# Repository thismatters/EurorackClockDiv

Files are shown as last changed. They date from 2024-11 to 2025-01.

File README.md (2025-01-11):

# Clock Divider (Binary)

This module reduces a clock signal by powers of two.

This is a hobbling together of elements featuring a three-layer stackup with a front face, a layer for all the jacks, and a power/processing layer where all the SMD components are layed out.

The input clock signal is passed through a schmitt trigger which is lifted whole-cloth from the [Yusynth Clock divider](https://yusynth.net/Modular/EN/DIVIDER/index.html) from which the reset signal processing is also lifted.
This module's function is distinct from the aforementioned Yusynth module in that it subdivides the clock by halves. The remainder of the circuit is a bog standard usage of the CD4040.

As with other modules in this line, this clock divider features:
* Polarity protection so that a backward power header doesn't fry anything (twin series schotty diodes: BAT54SL),
* Full surface mount design.

The KiCAD project here uses the library/footprints [found in my companion repo](https://github.com/thismatters/EurorackKiCAD).

## Width

11hp on an [Intellijel 1U rack](https://intellijel.com/support/1u-technical-specifications/).

## Inputs

Jacks:
* Input
* Reset

## Outputs

There are 6 output jacks each outputting a clock signal reduced by the labeled fraction.

## Adjustment

No adjustment required.

## Vendors

There are part numbers in the [BOM](clkdiv.csv) for many of the parts (not for basic passives though) at the following vendors:

* [Mouser](https://www.mouser.com): Needs no introduction. Get your ICs from here (or [digikey](https://www.digikey.com)).
* [Tayda Electronics](https://www.taydaelectronics.com/): Good supplier for passive components; audio jacks, and potentiometers. Their audio jacks are slightly smaller than the thonkiconn from thonk.
* [Love My Switches](https://lovemyswitches.com/): Has [really good knobs](https://lovemyswitches.com/anodized-aluminum-knob-the-lo-fi-1-4-smooth-shaft-12-5mm-od/) to go on those potentiometers!
* [OSHPark](https://oshpark.com/): Fast and (relatively) cheap PCB manufacturer. [V0 PCB](https://oshpark.com/shared_projects/ADWTtPJV)

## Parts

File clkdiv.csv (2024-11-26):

# | Reference | Qty | Value | Footprint | DNP | Vendor | PartNum
1 | C1, C2 | 2 | 22u 50V | Capacitor_THT:CP_Radial_D5.0mm_P2.50mm
2 | C3 | 1 | 100n | Capacitor_SMD:C_0805_2012Metric
3 | C4 | 1 | 47n box | Capacitor_THT:C_Rect_L7.2mm_W2.5mm_P5.00mm_FKS2_FKP2_MKS2_MKP2
4 | D1, D2 | 2 | BAT54S | Package_TO_SOT_SMD:SOT-23 |  | Mouser | 863-BAT54SLT1G
5 | D3, D4, D5 | 3 | 1N4148 | Diode_SMD:D_SOD-323_HandSoldering
6 | J1 | 1 | Conn_02x05_Odd_Even | Eurorack:PinHeader_2x05_P2.54mm_Vertical |  | Tayda | A-2939
7 | J2, J3, J4, J5, J6, J7, J8, J9 | 8 | AudioJack2_SwitchT | Eurorack:AudioJack2_Tayda_A-2566 |  | Tayda | A-2566
8 | J10, J12, J14 | 3 | Conn_01x03_Pin | Connector_PinHeader_2.54mm:PinHeader_1x03_P2.54mm_Vertical
9 | J11, J13, J15 | 3 | Conn_01x03_Socket | Connector_PinSocket_2.54mm:PinSocket_1x03_P2.54mm_Vertical
10 | Q3, Q4 | 2 | BCM847 | Package_SO:TSOP-6_1.65x3.05mm_P0.95mm |  | Mouser | 771-BCM847DS135
11 | R1, R2 | 2 | 10 | Resistor_SMD:R_0805_2012Metric
12 | R3, R9 | 2 | 1M | Resistor_SMD:R_0805_2012Metric
13 | R4 | 1 | 1.2M | Resistor_SMD:R_0805_2012Metric
14 | R5, R6, R12 | 3 | 22K | Resistor_SMD:R_0805_2012Metric
15 | R7 | 1 | 220 | Resistor_SMD:R_0805_2012Metric
16 | R8 | 1 | 100K | Resistor_SMD:R_0805_2012Metric
17 | R10 | 1 | 10K | Resistor_SMD:R_0805_2012Metric
18 | R11 | 1 | 220K | Resistor_SMD:R_0805_2012Metric
19 | R13, R14, R15, R16, R17, R18, R19 | 7 | 1K | Resistor_SMD:R_0805_2012Metric
20 | U1 | 1 | 4040 | Package_SO:TSSOP-16_4.4x5mm_P0.65mm |  | Mouser | 595-CD4040BPWR

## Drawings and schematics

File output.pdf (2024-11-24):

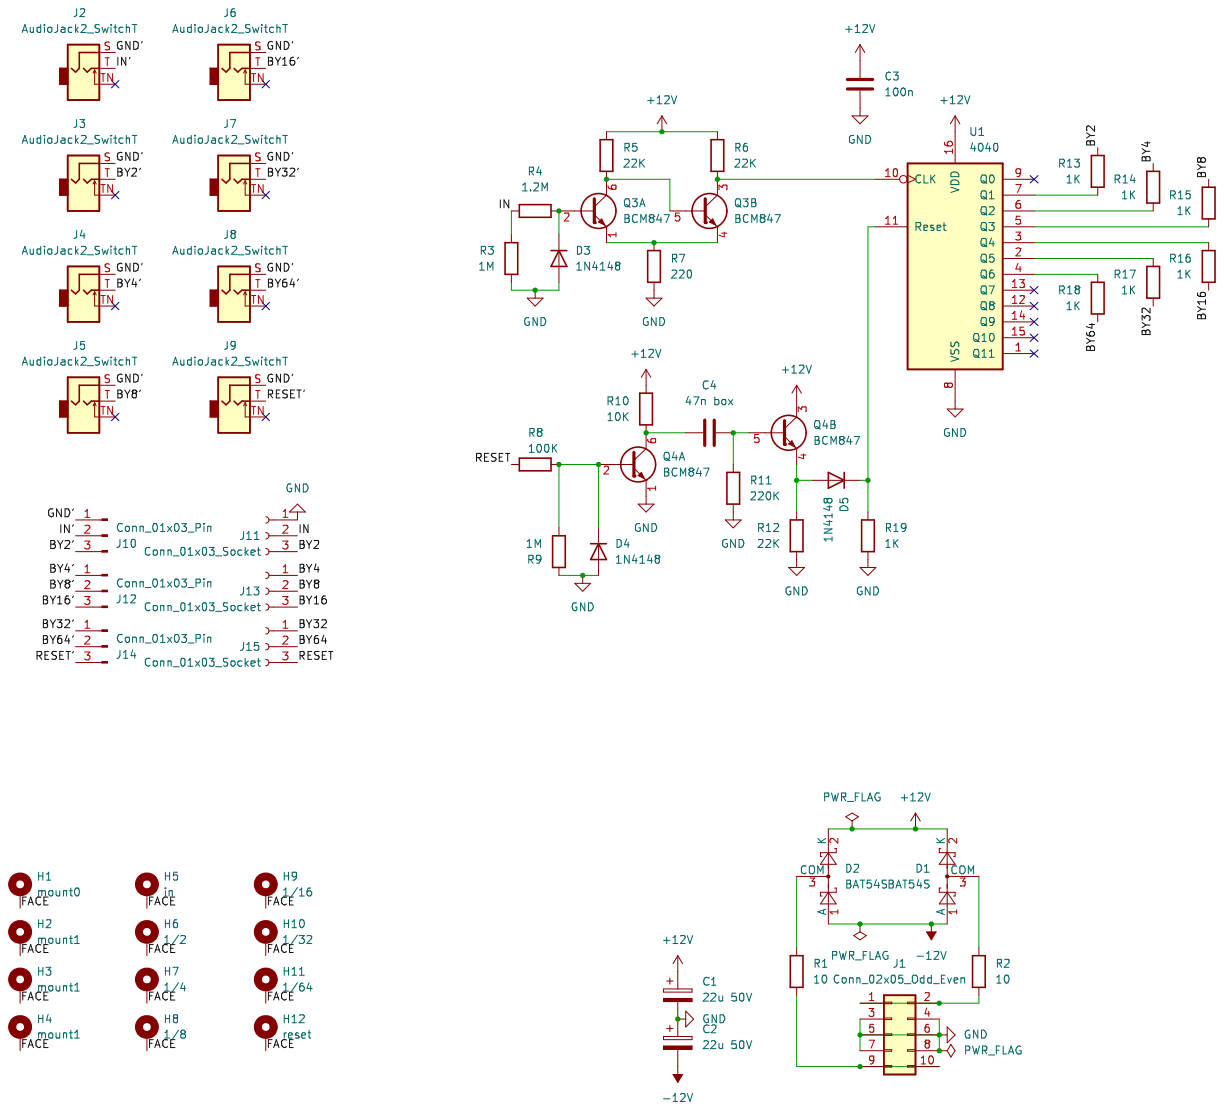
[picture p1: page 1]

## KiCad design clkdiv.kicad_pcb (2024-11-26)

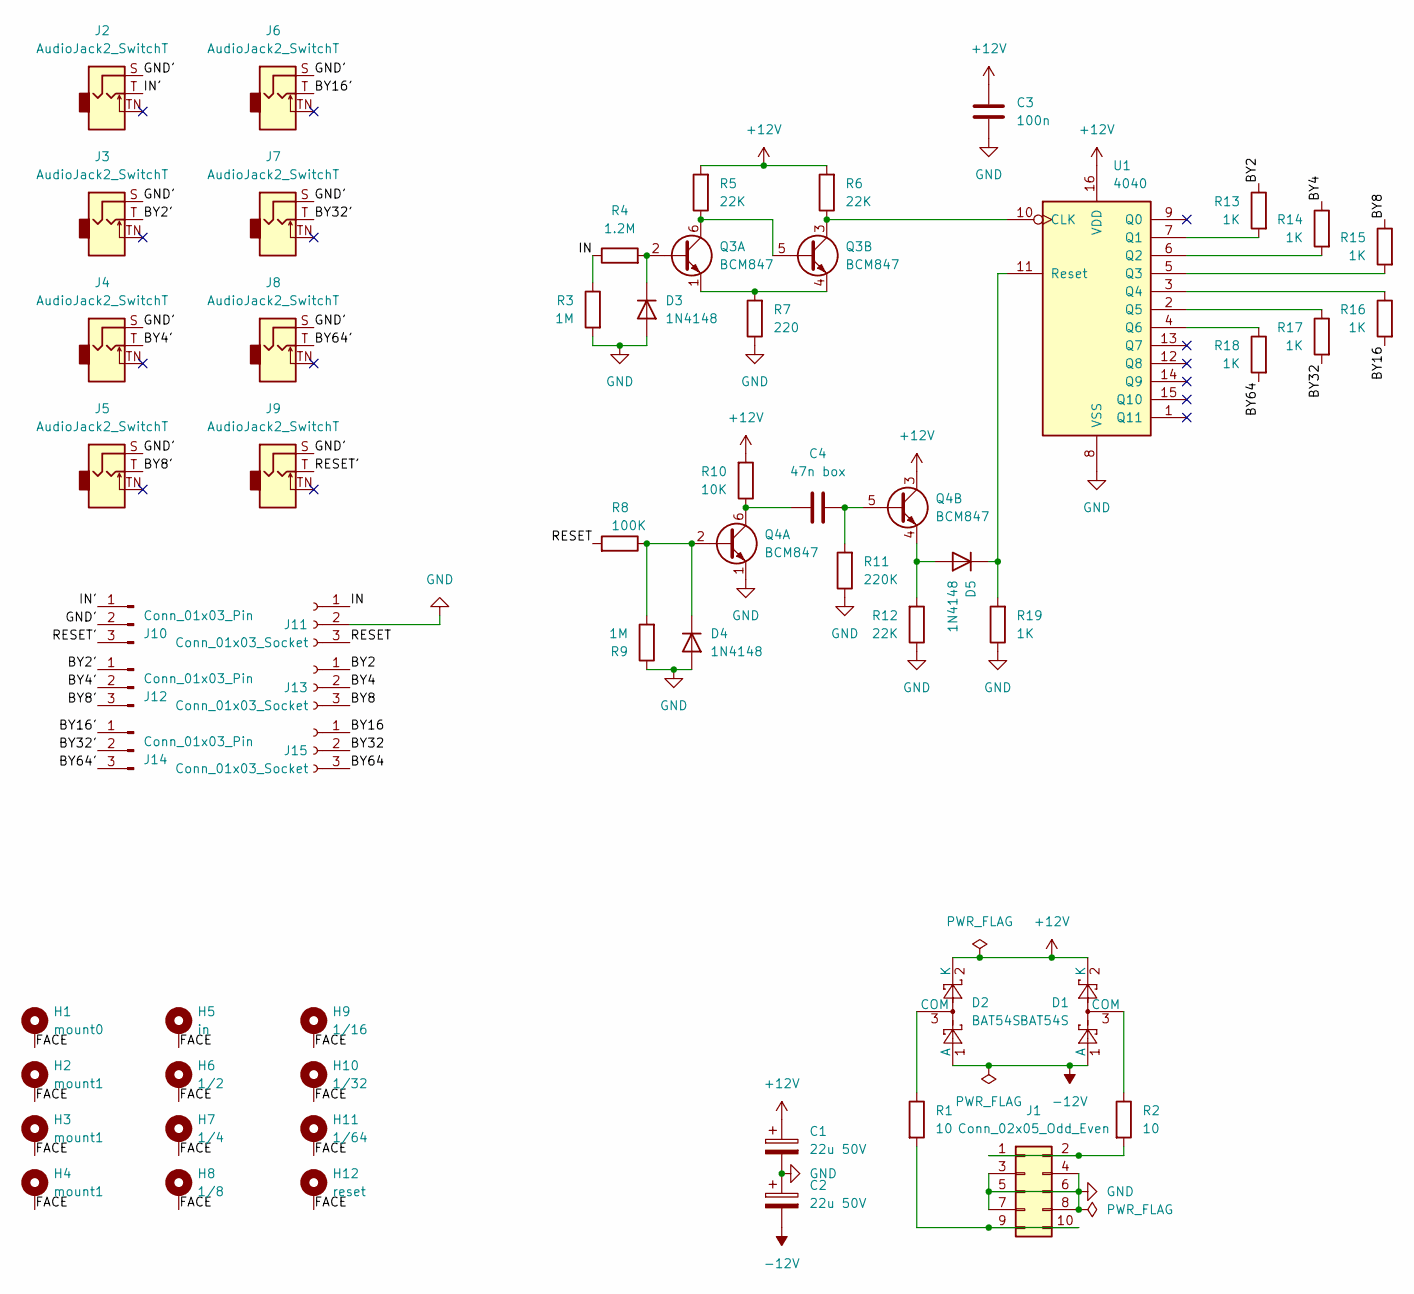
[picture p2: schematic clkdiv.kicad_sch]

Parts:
C1, C2: 22u 50V; CP_Radial_D5.0mm_P2.50mm
C3: 100n; C_0805_2012Metric
C4: 47n box; C_Rect_L7.2mm_W2.5mm_P5.00mm_FKS2_FKP2_MKS2_MKP2
D1, D2: BAT54S; SOT-23; PartNum 863-BAT54SLT1G
D3, D4, D5: 1N4148; D_SOD-323_HandSoldering
H1: mount0; Mech-MountingHole
H2, H3, H4: mount1; Mech-MountingHole
H5: in; Mech-AudioJack-Hole-Input-Clock
H6: 1/2; Mech-AudioJack-Hole-Output-Clock
H7: 1/4; Mech-AudioJack-Hole-Output-Clock
H8: 1/8; Mech-AudioJack-Hole-Output-Clock
H9: 1/16; Mech-AudioJack-Hole-Output-Clock
H10: 1/32; Mech-AudioJack-Hole-Output-Clock
H11: 1/64; Mech-AudioJack-Hole-Output-Clock
H12: reset; Mech-AudioJack-Hole-Input-Gate
J1: Conn_02x05_Odd_Even; PinHeader_2x05_P2.54mm_Vertical; PartNum A-2939
J2, J3, J4, J5, J6, J7, J8, J9: AudioJack2_SwitchT; AudioJack2_Tayda_A-2566; PartNum A-2566
J10, J12, J14: Conn_01x03_Pin; PinHeader_1x03_P2.54mm_Vertical
J11, J13, J15: Conn_01x03_Socket; PinSocket_1x03_P2.54mm_Vertical
Q3, Q4: BCM847; TSOP-6_1.65x3.05mm_P0.95mm; PartNum 771-BCM847DS135
R1, R2: 10; R_0805_2012Metric
R3, R9: 1M; R_0805_2012Metric
R4: 1.2M; R_0805_2012Metric
R5, R6, R12: 22K; R_0805_2012Metric
R7: 220; R_0805_2012Metric
R8: 100K; R_0805_2012Metric
R10: 10K; R_0805_2012Metric
R11: 220K; R_0805_2012Metric
R13, R14, R15, R16, R17, R18, R19: 1K; R_0805_2012Metric
U1: 4040; TSSOP-16_4.4x5mm_P0.65mm; PartNum 595-CD4040BPWR

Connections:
+12V: C1.1, C3.1, D1.2 (K), D2.2 (K), Q4.3 (C2), R5.2, R6.2, R10.2, U1.16 (VDD)
-12V: C2.2, D1.1 (A), D2.1 (A)
/BY2: J13.1, R13.1
/BY2': J3.T, J12.1
/BY4: J13.2, R14.1
/BY4': J4.T, J12.2
/BY8: J13.3, R15.1
/BY8': J5.T, J12.3
/BY16: J15.1, R16.2
/BY16': J6.T, J14.1
/BY32: J15.2, R17.2
/BY32': J7.T, J14.2
/BY64: J15.3, R18.2
/BY64': J8.T, J14.3
/FACE: H1.1, H2.1, H3.1, H4.1, H5.1, H6.1, H7.1, H8.1, H9.1, H10.1, H11.1, H12.1
/GND': J2.S, J3.S, J4.S, J5.S, J6.S, J7.S, J8.S, J9.S, J10.2
/IN: J11.1, R3.1, R4.1
/IN': J2.T, J10.1
/RESET: J11.3, R8.2
/RESET': J9.T, J10.3
GND: C1.2, C2.1, C3.2, D3.2 (A), D4.2 (A), J1.3, J1.4, J1.5, J1.6, J1.7, J1.8, J11.2, Q4.1 (E1), R3.2, R7.1, R9.1, R11.1, R12.1, R19.1, U1.8 (VSS)
unnamed: D1.3 (COM), R2.1
unnamed: D2.3 (COM), R1.1
unnamed: D3.1 (K), Q3.2 (B1), R4.2
unnamed: D4.1 (K), Q4.2 (B1), R8.1, R9.2
unnamed: D5.2 (A), Q4.4 (E2), R12.2
unnamed: D5.1 (K), R19.2, U1.11 (Reset)
unnamed: J1.1, J1.2, R2.2
unnamed: J1.9, J1.10, R1.2
unnamed: Q3.5 (B2), Q3.6 (C1), R5.1
unnamed: Q3.1 (E1), Q3.4 (E2), R7.2
unnamed: Q3.3 (C2), R6.1, U1.10 (CLK)
unnamed: C4.1, Q4.6 (C1), R10.1
unnamed: C4.2, Q4.5 (B2), R11.2
unnamed: R13.2, U1.7 (Q1)
unnamed: R14.2, U1.6 (Q2)
unnamed: R15.2, U1.5 (Q3)
unnamed: R16.1, U1.3 (Q4)
unnamed: R17.1, U1.2 (Q5)
unnamed: R18.1, U1.4 (Q6)

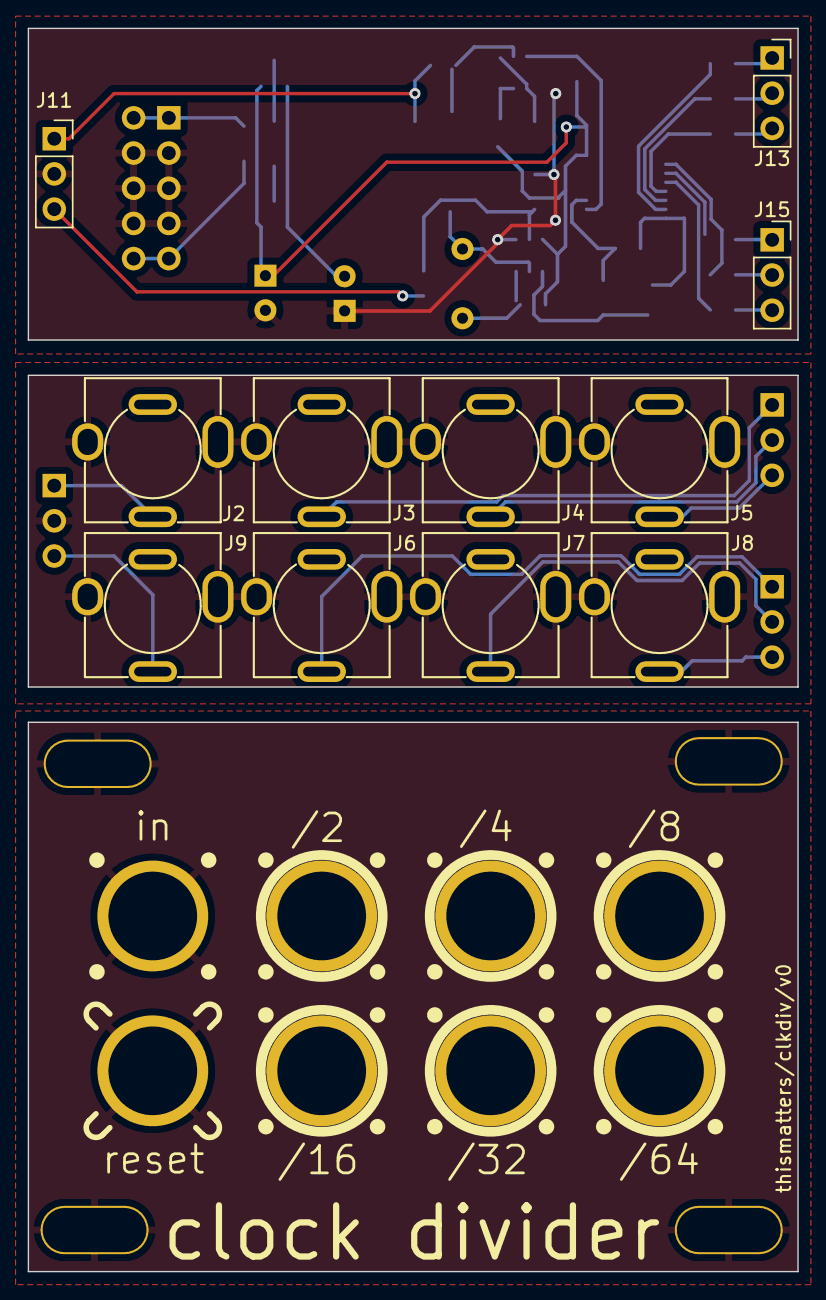
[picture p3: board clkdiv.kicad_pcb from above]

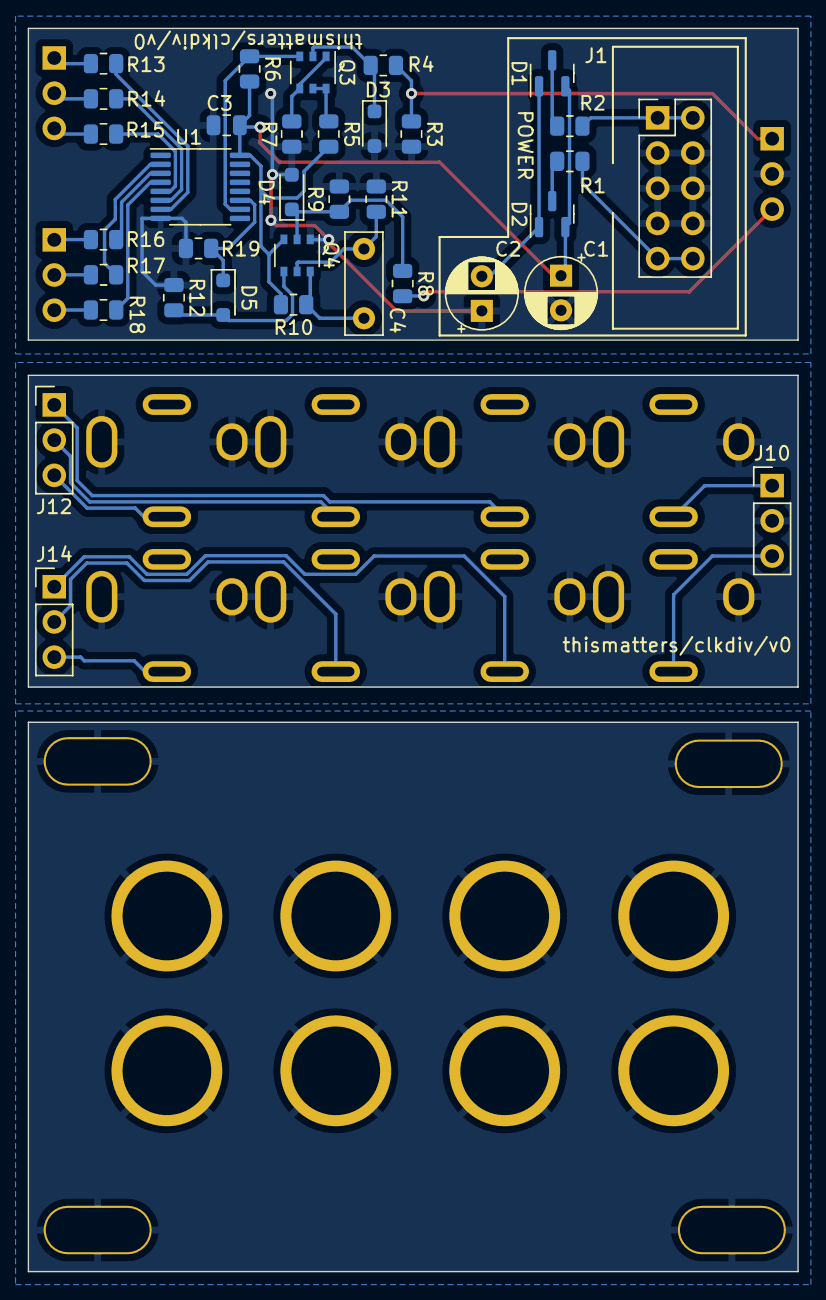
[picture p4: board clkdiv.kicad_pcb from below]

Board: 2 copper layers, 55.6 x 89.7 mm, 58 parts (35 on the bottom side), 40 nets.

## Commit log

2024-11-24 fixes after prototyping
    [clkdiv.kicad_sch]
2024-11-26 pcb laid out, bom generated
    [clkdiv.csv, clkdiv.kicad_pcb, clkdiv.kicad_sch]
2025-01-11 publish PCB
